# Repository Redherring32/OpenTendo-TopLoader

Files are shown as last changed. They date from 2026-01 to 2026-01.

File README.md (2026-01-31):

# OpenTendo-TopLoader
An Open Source HardWare (OSHW) recreation of the 1993 toploading NES motherboard (Also known as NES-101)

## Note on RGB and HDMI:

Neither RGB nor HDMI video output were or are a goal of the OpenTendo project, the goal was/is documentation and preservation, and the project was an exercise in reverse engineering. As such "improved" video outputs will not be added to OpenTendo-Toploader.

NESRGB and Hi-Def NES can be installed as normal, but will not be incorporated into the OpenTendo-Toploader PCB

## Repository Structure:

* Board Files: Contains all files necessary to open the project in KiCad, as well as the schematic and schematic symbols

* Component Footprints: Contains a library of all the custom footprints used on the board

The files required to order PCBs can be found under releases.

## Recommended PCB specs:

* 2 layers

* 106.1mmx155mm

* 1.6mm thickness

* HASL or ENiG surface finish

* And any color you want!

Board Front

Image credit: 1UpRestorations

The design is 1:1 with the OEM board, everything is exactly as it was on the OEM board with hopefully no exceptions, this project does not include "improvements"

Since this project is open-source you may do as you like with it, whether that is to make boards for personal use, sell replacement NES boards, or to use the provided info for further custom PCB work/designs.

*Note:* At this point in time, any and all motherboards will require the use of an original CPU[1],  and PPU[2] to function.
  
These are the only two chips that are custom and have no direct replacement, the rest can be replaced with modern, and or easily available parts.

*[1]There is an aftermarket CPU, the part number is UA6527 (NTSC) or UA6527P (PAL), however they are known to have different sounding audio due to swapped duty cycles, as such they aren't a 100% identical substitute, they otherwise work though.

*[2]There is an aftermarket PPU that can be used; the part number is UA6528 (NTSC) or UA6538 (PAL), and it is available on Aliexpress.
While it works as a drop-in replacement, it isn't known whether it is compatible with all NES games.

Please read the release page for notes on any parts that must be harvested, or otherwise obtained separately from the BOM.

## License:

Licensed under
the TAPR Open Hardware License (www.tapr.org/OHL)

©Redherring32 2022-2023

## Credits

* 1UpRestorations, RetroSho, and OGHUGO: "Beta" testing

* ShankMods, and Retrocution: donating motherboards for reverse engineering

And to all of the awesome people in the NES scene, I wouldn't have been able to do this without the awesome work that some very clever people did before I got here.

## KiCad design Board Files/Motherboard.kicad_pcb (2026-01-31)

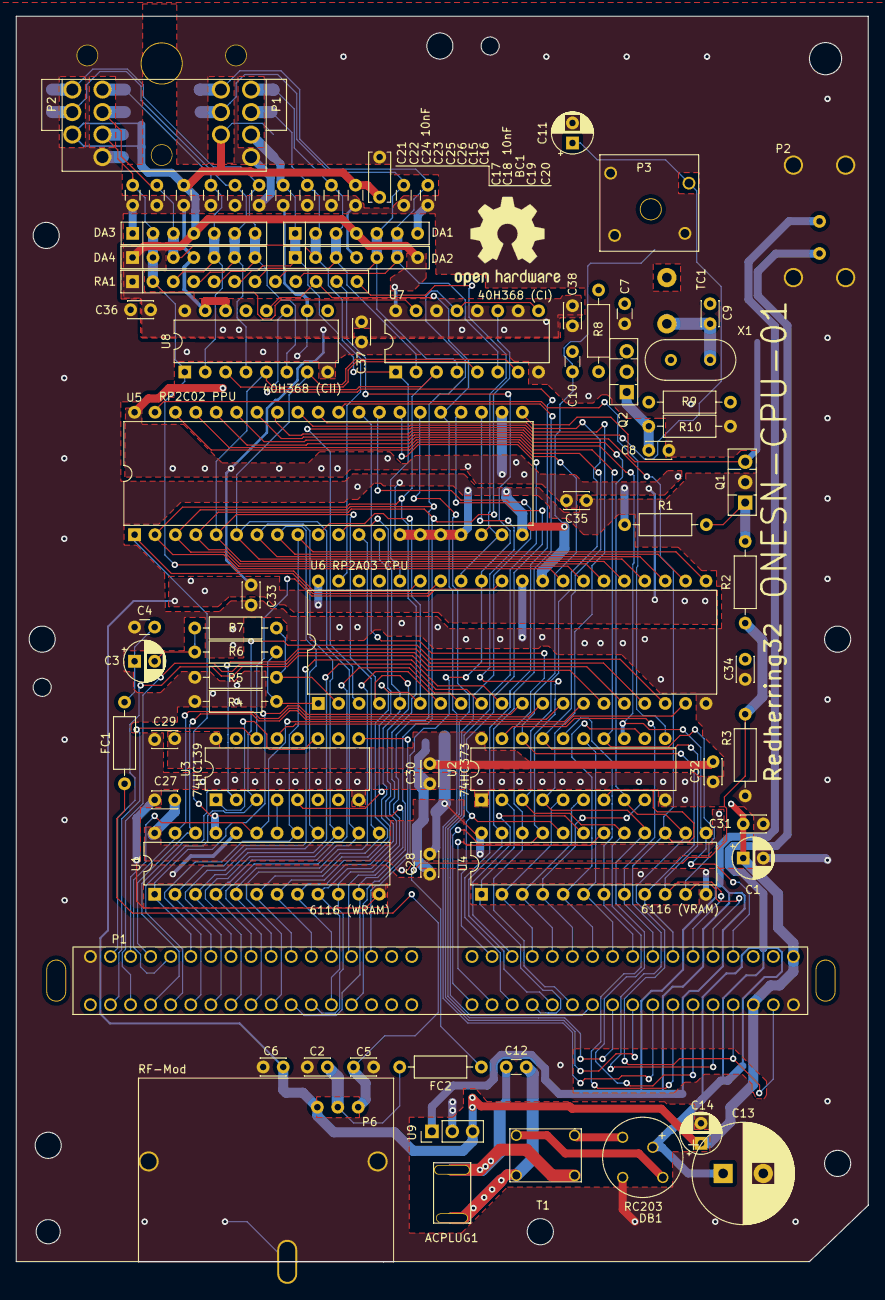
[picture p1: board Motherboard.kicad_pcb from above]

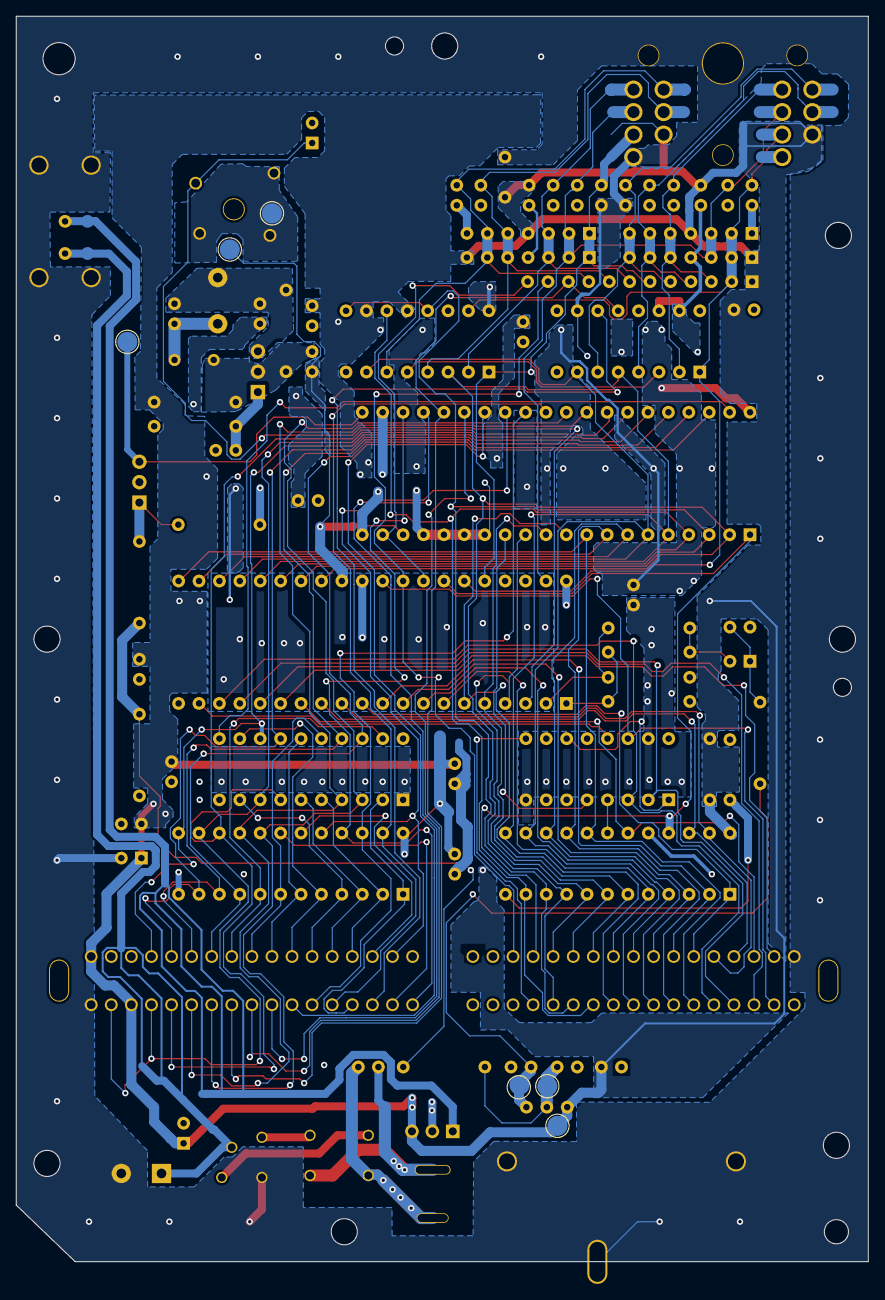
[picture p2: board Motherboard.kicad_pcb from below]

Board: 2 copper layers, 106.1 x 155.0 mm, 83 parts (6 on the bottom side), 92 nets.

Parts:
 : TestPoint_Pad_D2.5mm
 #2,  #3,  #4,  #5,  #6: TestPoint_Pad_D2.5mm
ACPLUG1: AC-JACK
BC1: 10nF; C_Disc_D6.0mm_W2.5mm_P5.00mm
C1: 100uF; CP_Radial_D5.0mm_P2.50mm
C2: 330pF; C_Disc_D3.0mm_W2.0mm_P2.50mm
C3, C14: 1uF; CP_Radial_D5.0mm_P2.50mm
C4: 220pF; C_Disc_D3.0mm_W1.6mm_P2.50mm
C5, C6, C8, C27, C28, C29, C30, C31, C32, C33, C34, C35, C36, C37, C38: 10nF; C_Disc_D3.0mm_W2.0mm_P2.50mm
C7, C15, C16, C17, C19, C20, C21, C22, C23, C25, C26: 330pF; C_Disc_D3.0mm_W1.6mm_P2.50mm
C9: 10pF; C_Disc_D3.0mm_W2.0mm_P2.50mm
C10, C12, C18, C24: 10nF; C_Disc_D3.0mm_W1.6mm_P2.50mm
C11: 0.47uF; CP_Radial_D5.0mm_P2.50mm
C13: 1500uF; CP_Radial_D12.5mm_P5.00mm
DA1, DA3: DAN601; R_Array_SIP7
DA2, DA4: UPA64H; R_Array_SIP7
DB1: RC203; Rectifier
FC1: 39u; R_Axial_DIN0207_L6.3mm_D2.5mm_P10.16mm_Horizontal
FC2: Ferrite_Coil; R_Axial_DIN0207_L6.3mm_D2.5mm_P10.16mm_Horizontal
P1: 72-Pin Connector; Cart Connector
P2: PowerSw; PowerSwitchV2
P3: ResetSw; ResetSwitchV2
P4: Controller_Port; Controller Ports
P6: RF-Mod; RF-MOD
Q1: 2SA937; TO-126-3_Vertical
Q2: 2SC2021; TO-126-3_Vertical
R1: 510; R_Axial_DIN0207_L6.3mm_D2.5mm_P10.16mm_Horizontal
R2: 430; R_Axial_DIN0207_L6.3mm_D2.5mm_P10.16mm_Horizontal
R3, R10: 150; R_Axial_DIN0207_L6.3mm_D2.5mm_P10.16mm_Horizontal
R4, R5: 160; R_Axial_DIN0207_L6.3mm_D2.5mm_P10.16mm_Horizontal
R6: 200; R_Axial_DIN0207_L6.3mm_D2.5mm_P10.16mm_Horizontal
R7: 100; R_Axial_DIN0207_L6.3mm_D2.5mm_P10.16mm_Horizontal
R8: 150K; R_Axial_DIN0207_L6.3mm_D2.5mm_P10.16mm_Horizontal
R9: 1.2K; R_Axial_DIN0207_L6.3mm_D2.5mm_P10.16mm_Horizontal
RA1: 12 x 10K; R_Array_SIP12
T1: 08RB01; Inductor
TC1: 30pF; TrimmerCap-THT
U1: 6116 (WRAM); DIP-24_W7.62mm
U2: 74HC373; DIP-20_W7.62mm
U3: 74HC139; DIP-16_W7.62mm
U4: 6116 (VRAM); DIP-24_W7.62mm
U5: RP2C02 PPU; DIP-40_W15.24mm
U6: RP2A03 CPU; DIP-40_W15.24mm
U7: 40H368 (CI); DIP-16_W7.62mm
U8: 40H368 (CII); DIP-16_W7.62mm
U9: L7805; PinHeader_1x03_P2.54mm_Vertical
X1: 21.47727 MHz; Crystal_HC49-U_Vertical

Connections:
/4016-D0: C17.1, DA1.3, DA2.3, P4.4-1, RA1.7, U7.2
/4016-D3: C19.1, DA1.5, DA2.5, P4.6-1, RA1.8, U7.4
/4016-D4: C20.1, DA1.6, DA2.6, P4.7-1, RA1.9, U7.6
/4017-D0: C23.1, DA3.5, DA4.5, P4.4-2, RA1.3, U8.2
/4017-D3: C25.1, DA3.6, DA4.6, P4.6-2, RA1.4, U8.4
/4017-D4: C26.1, DA3.7, DA4.7, P4.7-2, RA1.5, U8.6
/ALE: U2.11, U5.39
/AUDIO: #4.1, C5.1, FC1.1, P6.3
/CPU-A0: P1.13, U1.8, U5.12, U6.4
/CPU-A1: P1.12, U1.7, U5.11, U6.5
/CPU-A2: P1.11, U1.6, U5.10, U6.6
/CPU-A3: P1.10, U1.5, U6.7
/CPU-A4: P1.9, U1.4, U6.8
/CPU-A5: P1.8, U1.3, U6.9
/CPU-A6: P1.7, U1.2, U6.10
/CPU-A7: P1.6, U1.1, U6.11
/CPU-A8: P1.5, U1.23, U6.12
/CPU-A9: P1.4, U1.22, U6.13
/CPU-A10: P1.3, U1.19, U6.14
/CPU-A11: P1.2, U6.15
/CPU-A12: P1.39, U6.16
/CPU-A13: P1.40, U3.2, U6.17
/CPU-A14: P1.41, U3.3, U6.18
/CPU-A15: U3.13, U6.19
/CPU-D0: P1.49, U1.9, U5.2, U6.28, U7.3, U8.3
/CPU-D1: P1.48, U1.10, U5.3, U6.27, U7.9, U7.13
/CPU-D2: P1.47, U1.11, U5.4, U6.26, U7.11
/CPU-D3: P1.46, U1.13, U5.5, U6.25, U7.5, U8.5
/CPU-D4: P1.45, U1.14, U5.6, U6.24, U7.7, U8.7
/CPU-D5: P1.44, U1.15, U5.7, U6.23
/CPU-D6: P1.43, U1.16, U5.8, U6.22
/CPU-D7: P1.42, U1.17, U5.9, U6.21
/CPU-R~W: P1.14, U1.21, U5.1, U6.34
/GND: #2.1, BC1.1, C1.2, C2.1, C4.1, C5.2, C6.1, C7.1, C8.2, C11.2, C13.2, C14.2, C15.2, C16.2, C17.2, C18.2, C19.2, C20.2, C21.2, C22.2, C23.2, C24.2, C25.2, C26.2, C27.1, C28.1, C29.1, C30.1, C31.1, C32.1, C33.1, C34.1, C35.1, C36.1, C37.1, C38.1, DA1.7, DA2.4, DA3.1, DA4.4, DB1.2, P1.1, P1.72, P2.3, P3.2, P4.1-1, P4.1-2, P4.3, P4.4, P4.5, P6.4, Q1.2, R3.1, R4.1, R5.1, R10.2, U1.12, U1.20, U2.1, U2.10, U3.8, U3.15, U4.12, U5.14, U5.15, U5.16, U5.17, U5.20, U6.20, U6.30, U7.8, U8.8, U8.10, U8.14, U8.15, U9.2
/M2: P1.38, U3.14, U6.31
/OUT-0: C16.1, C22.1, DA1.2, DA2.2, DA3.3, DA4.3, P4.3-1, P4.3-2, U6.39
/PPU-A0: P1.29, U2.19, U4.8
/PPU-A1: P1.28, U2.16, U4.7
/PPU-A2: P1.27, U2.15, U4.6
/PPU-A3: P1.26, U2.12, U4.5
/PPU-A4: P1.25, U2.9, U4.4
/PPU-A5: P1.24, U2.6, U4.3
/PPU-A6: P1.23, U2.5, U4.2
/PPU-A7: P1.59, U2.2, U4.1
/PPU-A8: P1.60, U4.23, U5.30
/PPU-A9: P1.61, U4.22, U5.29
/PPU-A10: P1.63, U5.28
/PPU-A11: P1.62, U5.27
/PPU-A12: P1.64, U5.26
/PPU-A13: P1.65, RA1.10, U5.25, U8.12
/PPU-D0: P1.30, U2.18, U4.9, U5.38
/PPU-D1: P1.31, U2.17, U4.10, U5.37
/PPU-D2: P1.32, U2.14, U4.11, U5.36
/PPU-D3: P1.33, U2.13, U4.13, U5.35
/PPU-D4: P1.69, P1.71, U2.8, U4.14, U5.34
/PPU-D5: P1.68, U2.7, U4.15, U5.33
/PPU-D6: P1.67, U2.4, U4.16, U5.32
/PPU-D7: P1.66, U2.3, U4.17, U5.31
/PPU-~A13: P1.58, U8.11
/PPU-~CE: U3.5, U5.13
/PPU-~RD: P1.21, U4.20, U5.24
/PPU-~WE: P1.56, U4.21, U5.23
/SOUND-1: R4.2, R6.2, U6.1
/SOUND-2: R5.2, R7.2, U6.2
/SYS-CLK: .1, C10.1, U5.18, U6.29
/VCC: #6.1, BC1.2, C1.1, C6.2, C14.1, C18.1, C24.1, C27.2, C28.2, C29.2, C30.2, C31.2, C32.2, C33.2, C34.2, C35.2, C36.2, C37.2, C38.2, DA1.4, DA2.7, DA3.4, DA4.1, P1.36, P1.70, P4.5-1, P4.5-2, P6.1, R1.1, R9.2, RA1.1, U1.24, U2.20, U3.16, U4.24, U5.22, U5.40, U6.40, U7.10, U7.12, U7.14, U7.16, U8.16, U9.3
/VIDEO: #5.1, C2.2, FC2.2, P6.2
/VRAM-A10: P1.22, U4.19
/VRAM-~CE: P1.57, U4.18
/WRAM-~CE: U1.18, U3.4
/~IRQ: P1.15, RA1.11, U6.32
/~NMI: RA1.12, U5.19, U6.33
/~OE1: C15.1, DA1.1, DA2.1, P4.2-1, RA1.6, U6.36, U7.1
/~OE2: C21.1, DA3.2, DA4.2, P4.2-2, RA1.2, U6.35, U7.15, U8.1
/~ROMSEL: P1.50, U3.9
/~RST: C11.1, P3.1, U6.3
unnamed: ACPLUG1.1, C12.2, T1.1
unnamed: ACPLUG1.2, C12.1, T1.3
unnamed: C3.1, C4.2, FC1.2
unnamed: C3.2, R6.1, R7.1
unnamed: C7.2, C9.2, Q2.3, R8.2, TC1.2
unnamed: C8.1, Q2.1, R10.1
unnamed: C9.1, TC1.1, X1.2
unnamed: C10.2, Q2.2, R8.1, R9.1, X1.1
unnamed: C13.1, DB1.1, P2.1
unnamed: DB1.3, T1.4
unnamed: DB1.4, T1.2
unnamed: FC2.1, R2.1, R3.2
unnamed: P2.2, U9.1
unnamed: Q1.1, R1.2, R2.2
unnamed: #3.1, Q1.3, U5.21
unnamed: U3.1, U3.11

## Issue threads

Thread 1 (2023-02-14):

Discord reminder

ironsniper1, 2023-02-14:
Finny (grievre/arreffem) — Today at 9:58 PM
I found it thanks ❤️
@Redherring32 (The Fish) these are mislabeled, they're not shift registers. They're connected to shift registers (in the controllers), but the '368 is an inverting buffer/line driver chip

Redherring32 (The Fish) — Today at 10:01 PM
Hex buffers no? I meant to change that label actually but I'm a very forgetful person.

Finny (grievre/arreffem) — Today at 11:07 PM
Yeah. I would also label them 74HC368/40H368 since the latter is a weird Toshiba specific part number that wasn't even consistently used on the original hardware.

Redherring32, 2023-02-17:
Fixed in https://github.com/Redherring32/OpenTendo-TopLoader/commit/5f63f3e56a1f03a32ac05688f1c16b8a02da2a24

Closed 2023-02-17.

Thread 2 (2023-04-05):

Missing BOM items

NachtRaveVL, 2023-04-05:
Following components are listed in the schematic but missing from the BOM (under releases):
- DA1,DA2,DA3,DA4 (DAN601 diode arrays)
- TC1 (30pF)
- Q1 (2SA937) & Q2 (2SC2021)
- T1 (08RB01)

NachtRaveVL, 2023-04-05:
Nevermind I can't read correctly :p

Closed 2023-04-05.

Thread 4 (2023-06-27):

Missing C2 in bom

neo-snarl, 2023-06-27:
C2 seems to be missing in the bom.

neo-snarl, 2023-06-27:
Sorry found C2 in there.

Closed 2023-06-27.

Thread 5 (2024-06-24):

Pin37 sys-clk on cartridge connector unconnected?

bzuidgeest, 2024-06-24:
While looking over the schematic and PCB I noticed that pin 37 net sys-clk seems unconnected. Am I just missing something, or is this an error?

Looking at the schematic, that pin is Labeled System-clock not sys-clk like the others.

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

Redherring32, 2024-06-24:
Pin 37 is unconnected on the OEM board, and as such the pin should have been unlabeled or marked as NC in the schematic, but it seems I managed to forget doing that when I modified the OpenTendo schematic for this.

I'll try and fix it tonight, thank you for bringing this to my attention.

bzuidgeest, 2024-06-30:
Are you sure? sites like https://www.nesdev.org/wiki/Cartridge_connector very much show it connected. Source all over the internet vary in if they show it connected or not. The schematics on nesdev do not, but I have seen it connected in others. To bad nintendo is such a closed company otherwise we could just ask them.

Thank you for looking in to it.

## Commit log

2020-09-26 +Various schematic reference and net label fixes
    [Motherboard.sch]
2020-10-31 + Started board outline + Finished up the schematic (hopefully) + Started creation of custom footprints
    [Motherboard.kicad_pcb, Motherboard.sch]
2021-06-04 + Completed schematic + Added RF Modulator schematic symbol + Added RF Modulator footprint + Added Reset Switch footprint + Completed Power Switch footprint + Continued board layout
    [Motherboard.kicad_pcb, Motherboard.sch]
2021-06-11 + Added screw holes to PCB + Added holes to Cartridge and Controller footprints
    [Motherboard.kicad_pcb, Motherboard.sch]
2021-06-19 + Finished component layout + Tidied silkscreen
    [Motherboard.kicad_pcb, Motherboard.sch]
2023-01-12 Almost done
    + Added zone cutouts to make copper pours more like OEM shape
    + Edited schematic to be more readable
    TO-DO:
    * Finish cutouts
    * Verify mounting, alignment, and connector hole placement and sizing.
    [Motherboard.kicad_pcb, Motherboard.sch]
2023-01-14 + Fixed hole sizing and placement issues + Updated Cartridge connector, Controller Port, PowerSwitch, and ResetSwitch footprints to fix pad placement issues + Fixed overlapping reference labeling in 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
    [Motherboard.kicad_pcb, Motherboard.sch]
2023-02-10 + Implemented fixes for issues found in testing
    [Motherboard.kicad_pcb]
2023-02-17 Fix Issue #1
    [Motherboard.sch]
2026-01-31 + Migrate to Kicad 9 + Fix symbol issues caused by Kicad 6+ library and symbol name changes + Change "HEX BUFFERS" label to "CONTROLLER HEX BUFFERS" to match OpenTendo + Migrate legacy symbol .lib to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
    [Motherboard.kicad_pcb, Motherboard.kicad_sch, Motherboard.sch]
